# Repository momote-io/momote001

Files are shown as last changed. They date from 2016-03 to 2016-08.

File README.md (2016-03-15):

# The project momote001

We are creating a new line of products and development kits that enable and streamline the creation of applications for the Internet of Things (Iot).

The momote001 is ours first product. It will allow anyone to create wireless communications with applications to various areas. Mobility, health, trade, security, home automation, commercial, etc.

For while we are finalizing the necessary agreements and partneships needed to manufacture it in Brazil and sell at a competitive price. While the board does not come out of the oven, we are working to create the tools and development environments tha will be available. Help right now to create the plataform of the future and activily participate in the development community.

The final files for manufacturing and production momote001 are now available for anyone to study, manufacture and evolve the project.

# what is momote001?

momote001 CC2650 based IoT mote

# Contribution

To contribute visit: [momote001 forum](https://groups.google.com/forum/#!forum/momote-dev-br)

# License

The wiring diagram and the layout of the printed circuit board that were made in Circuit Maker and Altium are available under the CERN OHL v1.2 license.

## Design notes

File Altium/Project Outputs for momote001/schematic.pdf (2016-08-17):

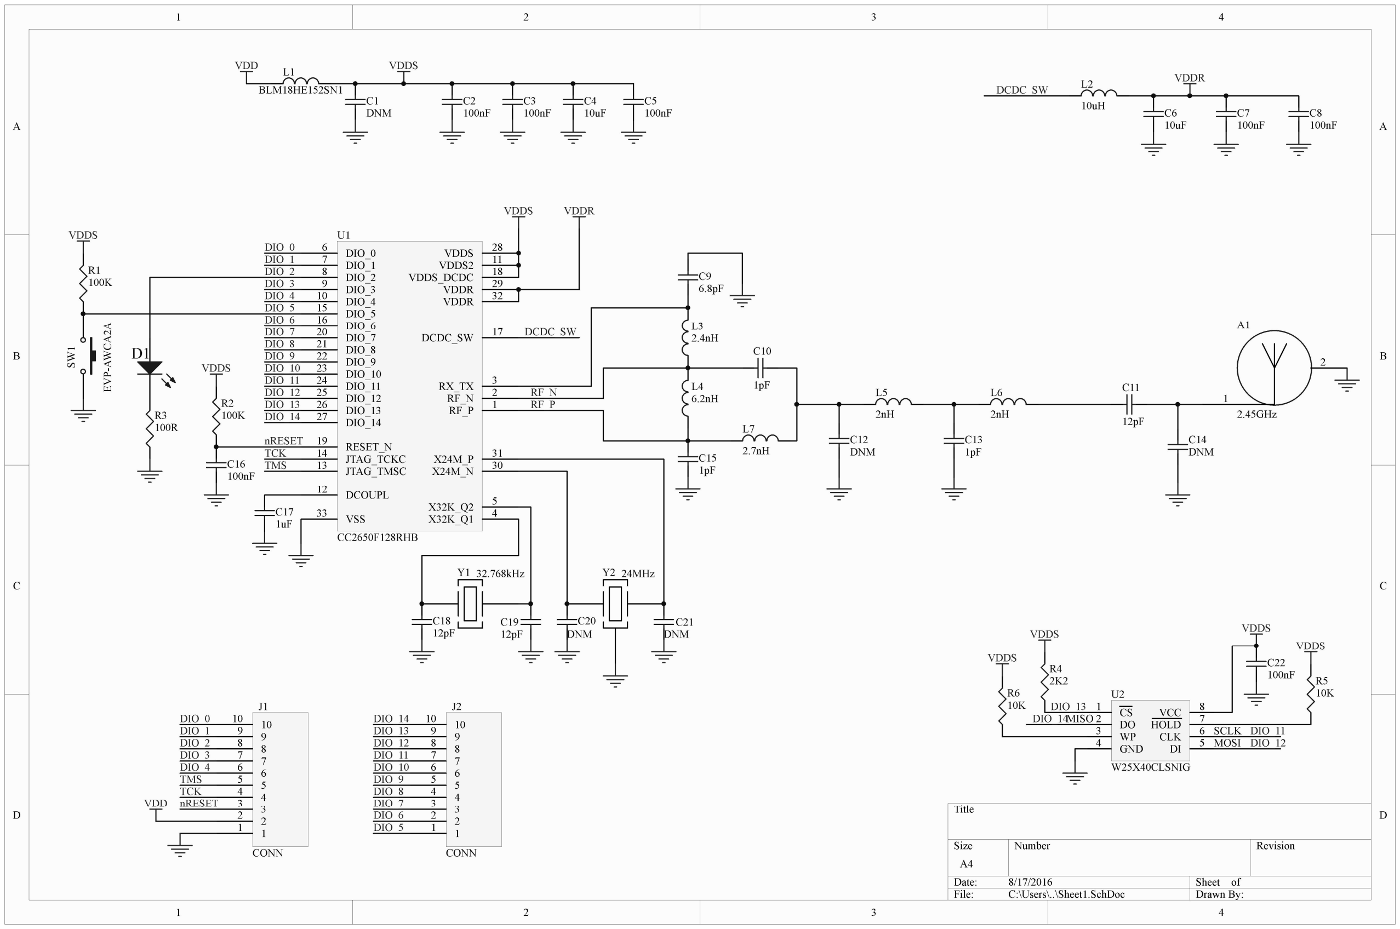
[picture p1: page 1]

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
Title
Size | Number | Revision
A4
Date: | 8/17/2016 | Sheet of
File: | C:\Users\..\Sheet1.SchDoc | Drawn By:

RX_TX 3

X32K_Q1 4

X32K_Q2 5

DIO_0 6
DIO_1 7
DIO_2 8
DIO_3 9
DIO_4 10

VDDS2 11

DCOUPL 12

JTAG_TMSC 13 JTAG_TCKC 14

DIO_5 15
DIO_6 16
DCDC_SW 17

VDDS_DCDC 18

RESET_N 19

DIO_7 20
DIO_8 21
DIO_9 22
DIO_10 23
DIO_11 24
DIO_12 25
DIO_13 26
DIO_14 27

VDDS 28
VDDR 29

X24M_N 30 X24M_P 31

VDDR 32

VSS 33

RF_P 1

RF_N 2

U1

CC2650F128RHB
Y1 32.768kHz | Y2 24MHz

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
10 10

J2

CONN

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
10 10

J1

CONN

DIO_0
DIO_2
DIO_3
DIO_4
DIO_5
DIO_6
DIO_7
DIO_8
DIO_9
DIO_10
DIO_11
DIO_12
DIO_13
DIO_14

DIO_1

DIO_0
DIO_2
DIO_3
DIO_4

DIO_5

DIO_6

DIO_7

DIO_8

DIO_9

DIO_10

DIO_11

DIO_12

DIO_13

DIO_14
DIO_1

TCK
TMS

TCK

TMS

nRESET

VDD nRESET

DCDC_SW

DCDC_SW | L2
10uH | C6
10uF

C7
100nF

C8
100nF

VDDS VDDR

C14
DNM

C21
DNM

C20
DNM

C19
12pF

C18
12pF

C17
1uF

C16
100nF

R2
100K

VDDS

L1
BLM18HE152SN1
C1
DNM

C2
100nF

C3
100nF

C4
10uF
VDD | VDDS
VDDR

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
2.7nH

D1

R3
100R

R1
100K

VDDS

CS 1
DO 2
WP 3
GND 4

VCC 8
HOLD 7
CLK 6
DI 5

U2

W25X40CLSNIG

VDDS

R5
10K

R4
2K2
R6
10K

VDDS

VDDS
VDDS

DIO_12

DIO_11

DIO_14

DIO_13

L3
2.4nH

C9
6.8pF

L4
6.2nH

C5
100nF

C11
12pF

MISO
MOSI

SCLK

1

2

A1
2.45GHz SW¹ EVP⁻AWCA²A

C22
100nF

RF_N
RF_P

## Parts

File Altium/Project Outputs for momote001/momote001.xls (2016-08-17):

Quantity | Designator | Details | DK PN | Manufacturer | MFG PN
1.0 | A1 | ANTENNA 2.4GHz INATEL
5.0 | C1, C12, C14, C20, C21
7.0 | C2, C3, C5, C7, C8, C16, C22 | CAP CER 0.1UF 6.3V 10% X7R 0402 | 490-6319-1-ND | Murata | GRM155R70J104KA01D
2.0 | C4, C6 | CAP CER 10UF 6.3V 20% X5R 0603 | 490-3896-1-ND | Murata | GRM188R60J106ME47D
1.0 | C9 | CAP CER 6.8PF 50V NP0 0402 | 490-5949-1-ND | Murata | GRM1555C1H6R8CA01D
3.0 | C10, C13, C15 | CAP CER 1PF 50V NP0 0402 | 490-6206-1-ND | Murata | GRM1555C1H1R0BA01D
3.0 | C11, C18, C19 | CAP CER 12PF 50V NP0 0402 | 490-5924-2-ND | Murata | GRM1555C1H120JA01D
1.0 | C17 | CAP CER 1UF 10V 10% X5R 0402 | 490-3890-1-ND | Murata | GRM155R61A105KE15D
1.0 | D1 | LED SUPER RED CLR THIN 0603 SMD | 160-1182-2-ND | Lite-On Inc | LTST-C190EKT
2.0 | J1, J2 | 10POS SIL VERTICAL PIN HEADER | 952-1843-ND | Harwin Inc | M20-9991046
1.0 | L1 | FERRITE CHIP 1500 OHM 500MA 0603 | 490-5216-1-ND | Murata | BLM18HE152SN1D
1.0 | L2 | FIXED IND 10UH 110MA 520 MOHM | 587-2608-1-ND | Taiyo Yuden | CKS2125100M-T
1.0 | L3 | FIXED IND 2.4NH 300MA 160 MOHM | 490-6559-1-ND | Murata | LQG15HN2N4S02D
1.0 | L4 | FIXED IND 6.2NH 300MA 220 MOHM | 490-2620-2-ND | Murata | LQG15HS6N2S02D
2.0 | L5, L6 | FIXED IND 2NH 300MA 100 MOHM SMD | 490-6569-1-ND | Murata | LQG15HS2N0S02D
1.0 | L7 | FIXED IND 2.7NH 300MA 150 MOHM | 490-2615-2-ND | Murata | LQG15HS2N7S02D
2.0 | R1, R2 | RES SMD 100K OHM 5% 1/10W 0402 | P100KJCT-ND | Panasonic | ERJ-2GEJ104X
1.0 | R3 | RES SMD 100 OHM 5% 1/10W 0402 | P100JTR-ND | Panasonic | ERJ-2GEJ101X
1.0 | R4 | RES SMD 2.2K OHM 5% 1/10W 0402 | P2.2KJTR-ND | Panasonic | ERJ-2GEJ222X
2.0 | R5, R6 | RES SMD 10K OHM 5% 1/10W 0402 | P10KJTR-ND | Panasonic | ERJ-2GEJ103X
1.0 | SW1 | Tactile Switch SPST-NO Top Actuated Surface Mount | P16851CT-ND | Panasonic | EVP-AWCA2A
1.0 | U1 | IC MCU 128KB FLASH PHY 32VQFN | 296-41955-1-ND | TI | CC2650F128RHBT
1.0 | U2 | IC FLASH 4MBIT 104MHZ 8SOIC | W25X40CLSNIG TR-ND | Winbond | W25X40CLSNIG TR
1.0 | Y1 | Crystal 32.7680kHz 20ppm 12.5pF 90 kOhm -40°C - 85°C Surface Mount 2-SMD | SER3672CT-ND | EPSON | FC-12M 32.7680KA-A3
1.0 | Y2 | Crystal 24.0000MHz 10ppm 9pF 40 Ohm -40°C - 85°C Surface Mount 4-SMD, No Lead (DFN, LCC) | SER3635CT-ND | EPSON | TSX-3225 24.0000MF15X-AC3

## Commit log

2015-11-28 fix for production
    [PCB1.PcbDoc, Sheet1.SchDoc]
2015-12-08 release r3
    [PCB1.PcbDoc, Sheet1.SchDoc, momote001.PrjPcb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]
2016-03-02 adjustments for 1st pilot batch
    [PCB1.PcbDoc, Sheet1.SchDoc, momote001.PrjPcb]
2016-03-04 new antenna
    [PCB1.PcbDoc, Sheet1.SchDoc, momote001.PrjPcb]
2016-03-14 documentação e organização do projeto
    [PCB1.PcbDoc, Sheet1.SchDoc, momote001.PrjPcb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]
2016-03-15 rename schematics dir
    [PCB1.PcbDoc, Sheet1.SchDoc, momote001.PrjPcb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]
2016-03-15 remove references from lib
    [momote001.PrjPcb]
2016-03-24 fix antenna mechanical drawings
    [PCB1.PcbDoc]
2016-03-24 fix stencil for fabrication
    [PCB1.PcbDoc]
2016-04-06 change fiducial, silk, vias
    [PCB1.PcbDoc]
2016-08-17 fix info for SW, flash, antenna and generate BOM
    [PCB1.PcbDoc, Sheet1.SchDoc, momote001.xls]
2016-08-17 remove gerber zip
2016-08-17 regenerate schematic
